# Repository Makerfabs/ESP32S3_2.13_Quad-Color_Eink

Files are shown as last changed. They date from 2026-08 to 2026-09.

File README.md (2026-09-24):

# MaTouch ESP32-S3 2.13 Quad-Color Eink

## Introduction

Our MaTouch ESP32-S3 2.13 Quad-Color E-Ink display is equipped with the KEGM021317E08 model from Qingyue Optoelectronics, which adopts active matrix TFT microcapsule electrophoretic display technology to render images. This technology operates by applying an electric field to charged pigment particles suspended inside transparent microcapsules. Colored particles migrate to the microcapsule surfaces and reflect ambient light to form visible patterns, delivering a paper-like viewing experience identical to physical printed media. The EPD module features an active area resolution of 250(H) × 122(V) pixels, supporting 1-bit four-color display mode: black, white, red and yellow. Onboard peripheral expansion integrates the QMI8658A IMU sensor, which provides high-precision six-axis accelerometer and gyroscope data for motion detection, posture sensing and interactive control development.

Product Link: [MaTouch ESP32-S3 2.13 Quad-Color Eink](https://www.makerfabs.com/matouch-esp32-s3-2-13-quad-color-eink-epaper.html)

Wiki Link:  [MaTouch ESP32-S3 2.13 Quad-Color Eink](https://wiki.makerfabs.com/MaTouch%20ESP32_S3%202.13%20Quad_Color%20Eink.html)

Example：1.[SD_pic_display](https://github.com/Makerfabs/ESP32S3_2.13_Quad-Color_Eink#sd_pic_display)

2.[EPD_Pose_Display](https://github.com/Makerfabs/ESP32S3_2.13_Quad-Color_Eink#epd_pose_display)

## LCD Specs:

- PART NUMBER：KEGM021317E08
- SIZE：2.13 inch
- TYPE：Dot Matrix
- IC：JD79676
- RESOLUTION：250 × 122
- OUTLINE SIZE (mm)：75.2 × 29.2 × 0.911
- ACTIVE SIZE (mm)：48.55 × 23.7046
- PIXEL PITCH (mm)：0.1942 × 0.1943
- OPERATING TEMP.：0°C ~ 40°C
- STORAGE TEMP.：-25°C ~ 60°C
- CONNECTOR：24 Pin FPC
- COLOR：Black, White, Red, Yellow
- INTERFACE：SPI
- FULL REFRESH (S)：20

## Features

- Controller: ESP32-S3
- Wireless: WiFi& Bluetooth 5.0
- Flash:16MB Flash
- PSRAM:8MB
- MICRO SD: Yes
- IMU:QMI8658A
- USB:1 * USB_native
- Arduino support: Yes

## Example

### SD_pic_display

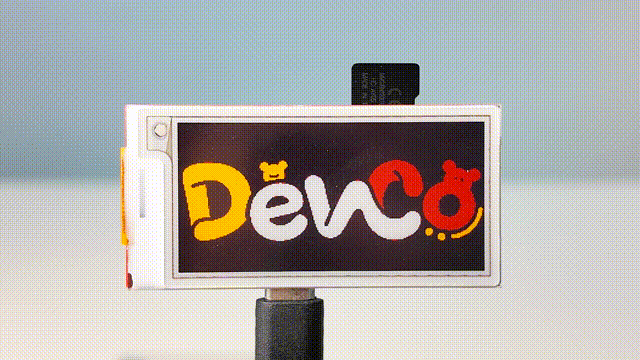
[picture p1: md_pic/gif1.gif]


For details of this example, please refer to the [Wiki](https://wiki.makerfabs.com/MaTouch%20ESP32_S3%202.13%20Quad_Color%20Eink.html#41-sd_pic_display) document.

### EPD_Pose_Display

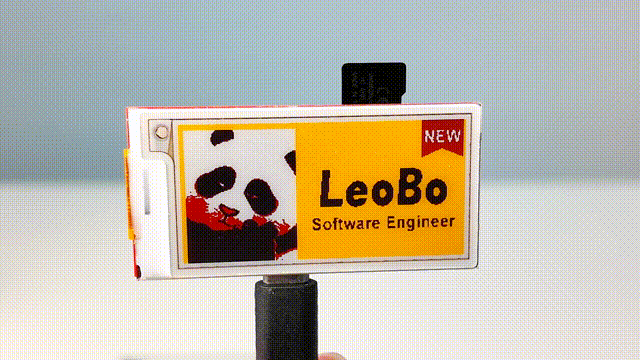
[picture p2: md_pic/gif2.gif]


For details of this example, please refer to the [Wiki](https://wiki.makerfabs.com/MaTouch%20ESP32_S3%202.13%20Quad_Color%20Eink.html#42-epd_pose_display) document.

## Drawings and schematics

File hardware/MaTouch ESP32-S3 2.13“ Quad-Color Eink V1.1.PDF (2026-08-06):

# POWER

# USB

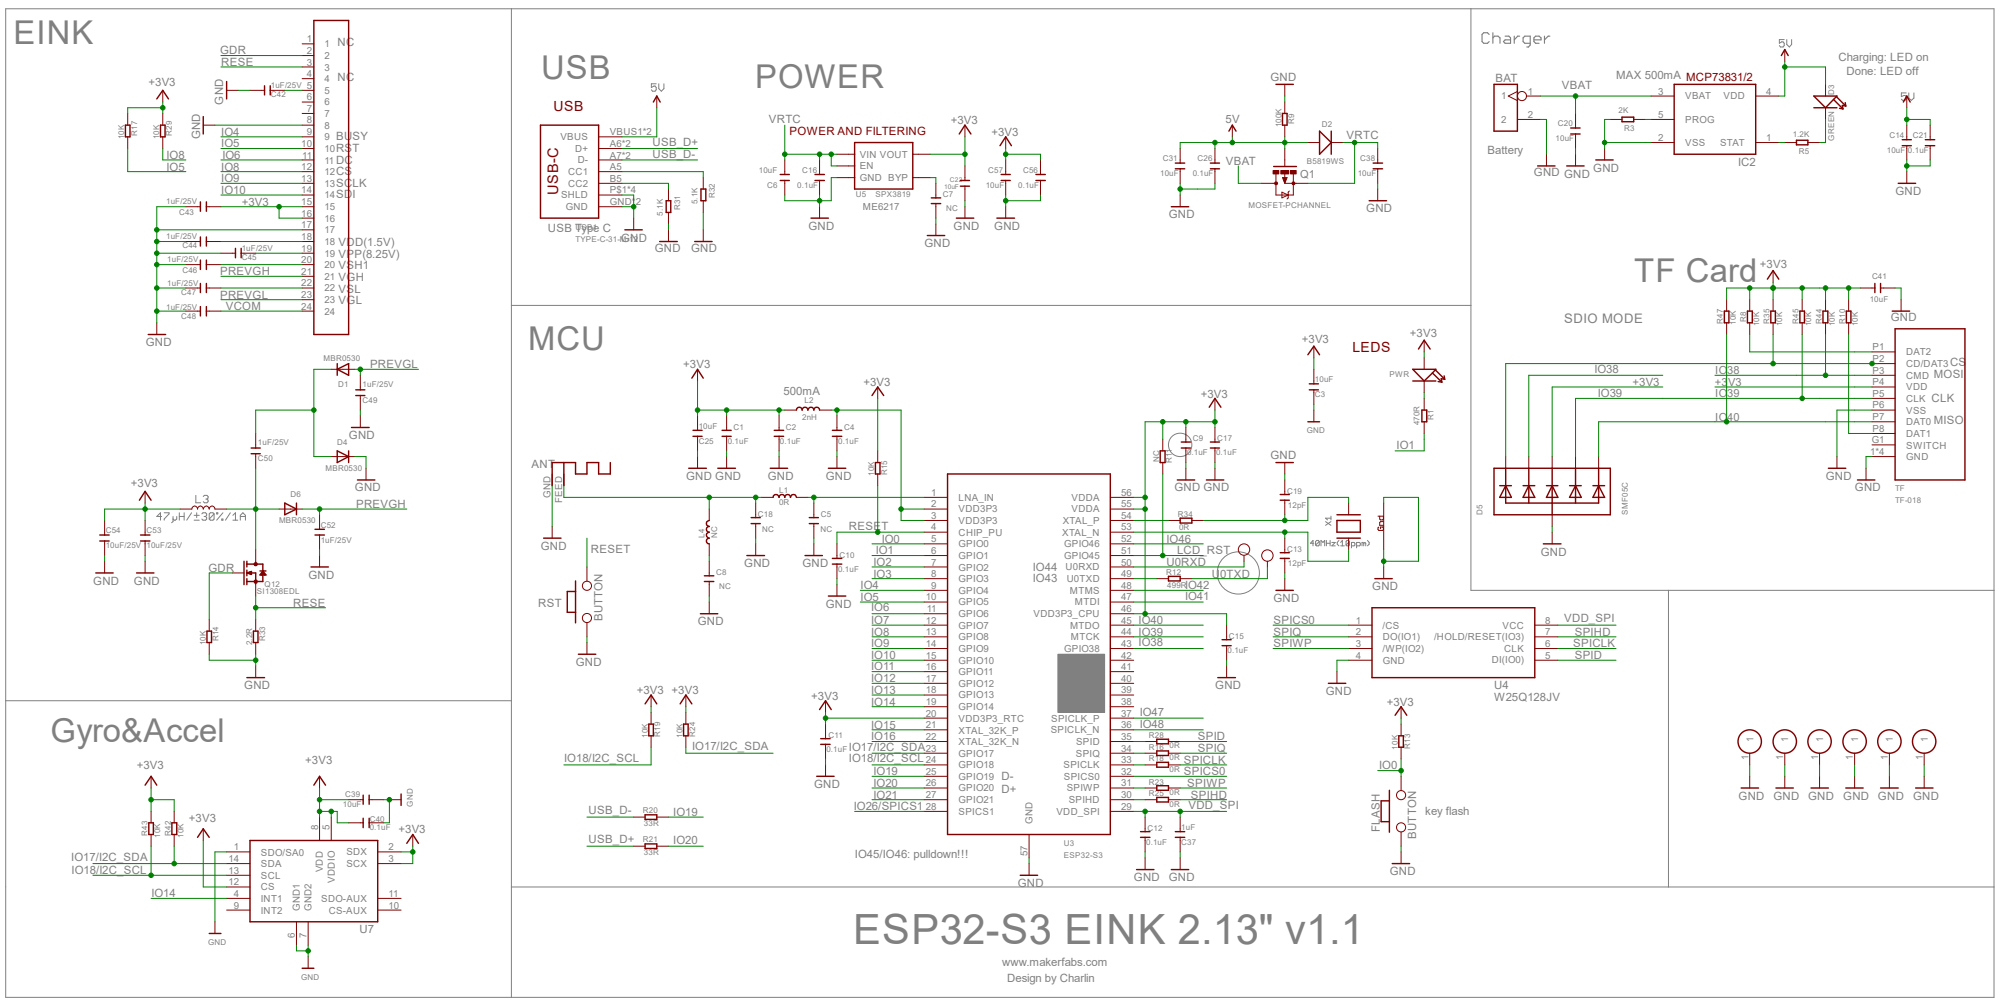
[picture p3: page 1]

VSS P6

DAT1 P8

GND GND

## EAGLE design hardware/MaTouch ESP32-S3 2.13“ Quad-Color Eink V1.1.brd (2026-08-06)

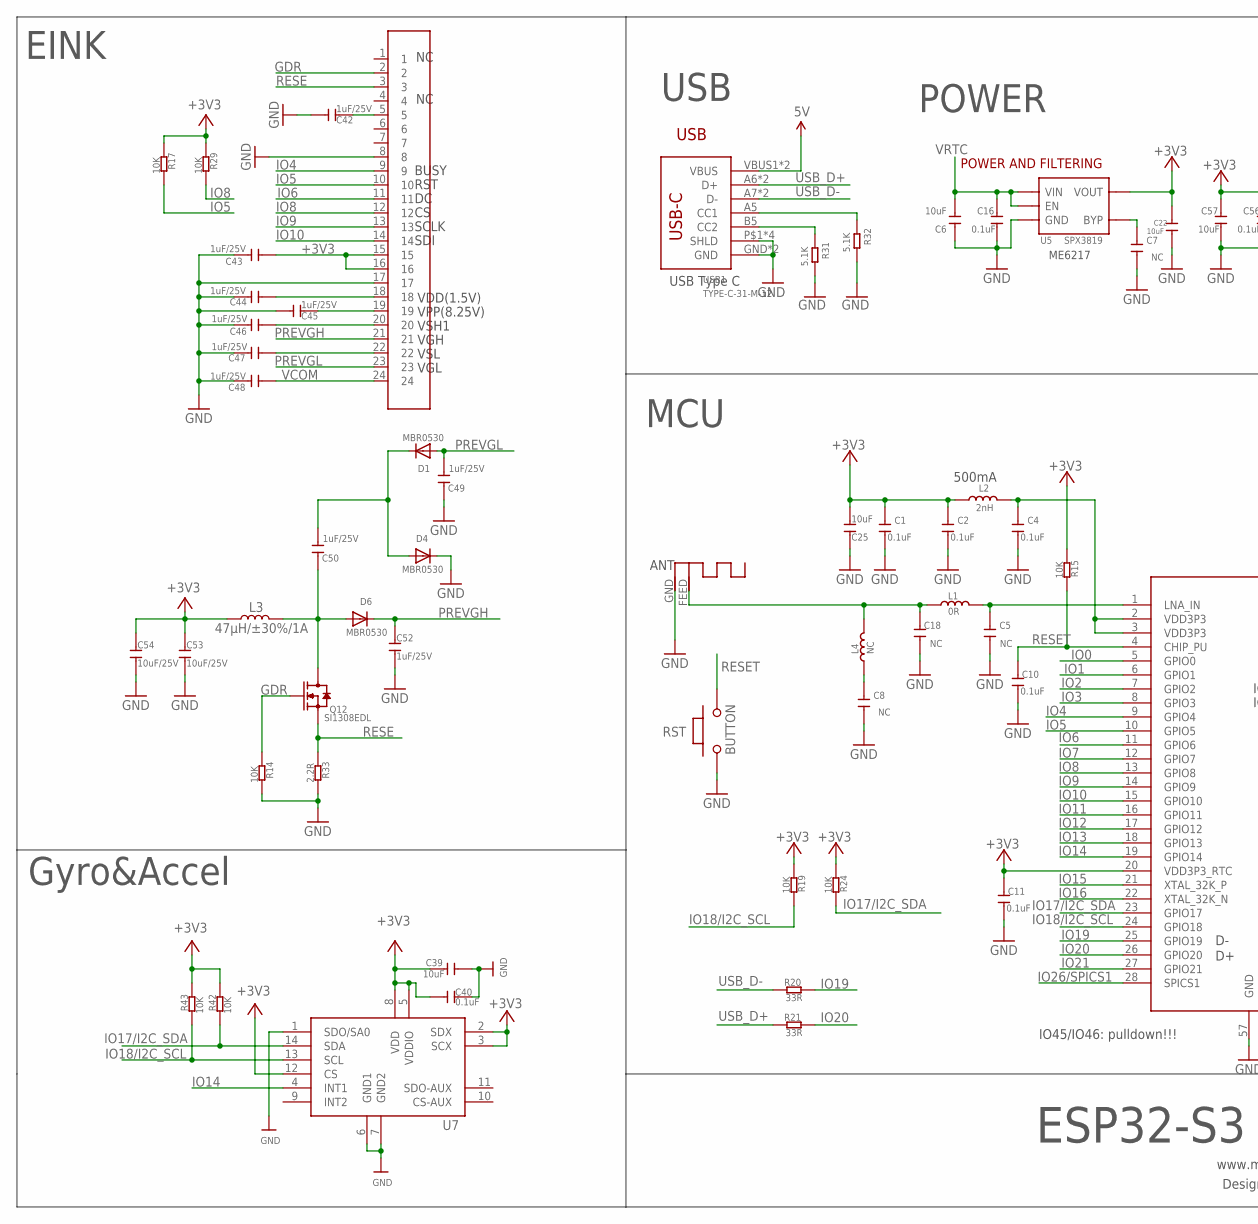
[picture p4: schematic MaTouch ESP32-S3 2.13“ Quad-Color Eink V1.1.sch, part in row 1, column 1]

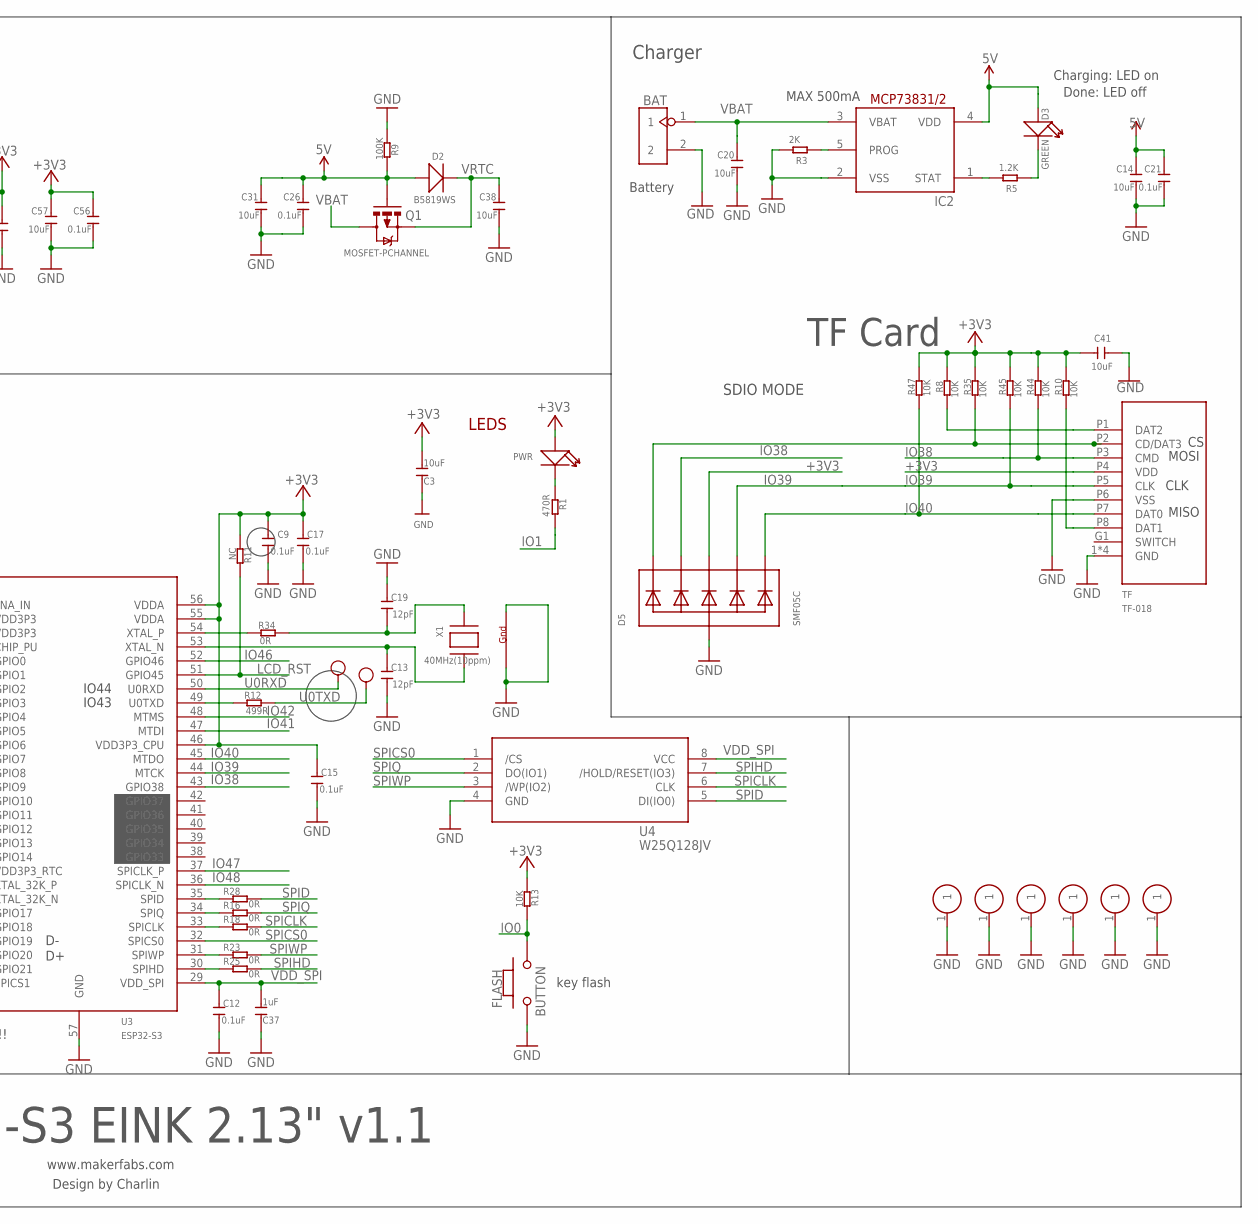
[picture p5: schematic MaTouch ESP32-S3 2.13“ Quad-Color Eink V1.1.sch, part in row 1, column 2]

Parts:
ANT1: ANTENNA; RN-ANT
BAT: HEADER-2P-2.0; 2P-2.0
C1, C2, C4, C9, C10, C11, C12, C15, C16, C17, C21, C26, C40, C56: 0.1uF; DISCRETE_C0402
C3, C6, C25: 10uF; DISCRETE_C0603
C5, C7, C8, C18: NC; DISCRETE_C0402
C13, C19: 12pF; DISCRETE_C0402
C14, C20, C31, C38, C39, C41, C57: 10uF; DISCRETE_C0402
C22: 10uF; 0603
C37: 1uF; DISCRETE_C0603
C42, C43, C44, C45, C46, C47, C48, C49, C50: 1uF/25V; DISCRETE_C0402
C52: 1uF/25V; 0603
C53, C54: 10uF/25V; 0603
D1, D4, D6: MBR0530; SOD-323F
D2: B5819WS; SOD323
D3: GREEN; DISCRETE_LED-0603
D5: SMF05C; SOT363
FLASH: BUTTON; 157SW
IC2: TP4054; SOT23-5L
J1: FPC24-80P-A; SMD24-80P-1960L440W
L1: 0R; DISCRETE_L0402
L2: 2nH; DISCRETE_L0603
L3: 47µH/±30%/1A; CR54
L4: NC; DISCRETE_L0402
PWR: DISCRETE_LED0603; DISCRETE_LED-0603
Q1: MOSFET-PCHANNEL; SOT23-3
Q12: SI1308EDL; SOT23
R1: 470R; DISCRETE_R0402
R3: 2K; DISCRETE_R0402
R5: 1.2K; DISCRETE_R0402
R8, R10, R13, R14, R15, R17, R19, R24, R29, R35, R42, R43, R44, R45, R47: 10K; DISCRETE_R0402
R9: 100K; DISCRETE_R0402
R11: NC; DISCRETE_R0402
R12: 499R; DISCRETE_R0402
R16, R18, R23, R25, R28, R34: 0R; DISCRETE_R0402
R20, R21: 33R; DISCRETE_R0402
R31, R32: 5.1K; DISCRETE_R0402
R33: 2.2R; DISCRETE_R0402
RST: BUTTON; 157SW
RX: TEST-POINT'4545'; TP-D45MIL; PARTNO DNP
S1, S2, S3, S4, S5, S6: ONEPIN01
TF: TF-018
TX: TEST-POINT'4545'; TP-D45MIL; PARTNO DNP
U3: ESP32-S3; QFN56-7*7MM
U4: W25Q128JV; SOIC-8-208MIL
U5: SPX3819; SOT23-5
U7: QMI8658A; LGA14-50P-300L250W86H
USB1: TYPE-C-31-M-12
X1: 40MHz(10ppm); NX3225

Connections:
5V: C14.2, C21.2, C26.2, C31.2, D2.+, D3.+, IC2.4 (VDD), Q1.1 (G), R9.2, USB1.VBUS1 (VBUS), USB1.VBUS2 (VBUS)
+3V3: C1.2, C2.2, C3.2, C9.2, C11.2, C15.2, C17.2, C22.1, C25.2, C39.2, C40.2, C41.2, C43.1, C53.1, C54.1, C56.2, C57.2, D5.4 (C3), J1.15, J1.16, L2.1, L3.P$1 (1), PWR.+, R8.2, R10.2, R11.2, R13.2, R15.2, R17.1, R19.2, R24.2, R29.1, R35.2, R42.2, R43.2, R44.2, R45.2, R47.2, TF.P4 (VDD), U3.20 (VDD3P3_RTC), U3.46 (VDD3P3_CPU), U3.55 (VDDA), U3.56 (VDDA), U5.5 (VOUT), U7.2 (SDX), U7.3 (SCX), U7.5 (VDDIO), U7.8 (VDD), U7.12 (CS)
GDR: J1.2, Q12.1 (G), R14.1
GND: ANT1.GND, BAT.2, C1.1, C2.1, C3.1, C4.1, C5.1, C6.1, C7.1, C8.1, C9.1, C10.1, C11.1, C12.1, C13.1, C14.1, C15.1, C16.1, C17.1, C18.1, C19.2, C20.1, C21.1, C22.2, C25.1, C26.1, C31.1, C37.1, C38.1, C39.1, C40.1, C41.1, C42.2, C43.2, C44.2, C45.2, C46.2, C47.2, C48.2, C49.2, C52.2, C53.2, C54.2, C56.1, C57.1, D4.C, D5.2 (A), FLASH.1, IC2.2 (VSS), J1.8, J1.17, R3.2, R9.1, R14.2, R31.2, R32.2, R33.2, RST.1, S1.1, S2.1, S3.1, S4.1, S5.1, S6.1, TF.1 (GND), TF.2 (GND), TF.3 (GND), TF.4 (GND), TF.P6 (VSS), U3.57 (GND), U4.4 (GND), U5.2 (GND), U7.1 (SDO/SA0), U7.6 (GND1), U7.7 (GND2), USB1.GND, USB1.GND2 (GND), USB1.P$1 (SHLD), USB1.P$2 (SHLD), USB1.P$3 (SHLD), USB1.P$4 (SHLD), X1.2 (G2), X1.4 (G1)
IO0: FLASH.2, R13.1, U3.5 (GPIO0)
IO1: R1.1, U3.6 (GPIO1)
IO2: U3.7 (GPIO2)
IO3: U3.8 (GPIO3)
IO4: J1.9, U3.9 (GPIO4)
IO5: J1.10, R17.2, U3.10 (GPIO5)
IO6: J1.11, U3.11 (GPIO6)
IO7: U3.12 (GPIO7)
IO8: J1.12, R29.2, U3.13 (GPIO8)
IO9: J1.13, U3.14 (GPIO9)
IO10: J1.14, U3.15 (GPIO10)
IO11: U3.16 (GPIO11)
IO12: U3.17 (GPIO12)
IO13: U3.18 (GPIO13)
IO14: U3.19 (GPIO14), U7.4 (INT1)
IO15: U3.21 (XTAL_32K_P)
IO16: U3.22 (XTAL_32K_N)
IO17/I2C_SDA: R24.1, R42.1, U3.23 (GPIO17), U7.14 (SDA)
IO18/I2C_SCL: R19.1, R43.1, U3.24 (GPIO18), U7.13 (SCL)
IO19: R20.1, U3.25 (GPIO19)
IO20: R21.1, U3.26 (GPIO20)
IO21: U3.27 (GPIO21)
IO26/SPICS1: U3.28 (SPICS1)
IO38: D5.3 (C2), R44.1, TF.P3 (CMD), U3.43 (GPIO38)
IO39: D5.5 (C4), R45.1, TF.P5 (CLK), U3.44 (MTCK)
IO40: D5.6 (C5), R47.1, TF.P7 (DAT0), U3.45 (MTDO)
IO41: U3.47 (MTDI)
IO42: U3.48 (MTMS)
IO46: U3.52 (GPIO46)
IO47: U3.37 (SPICLK_P)
IO48: U3.36 (SPICLK_N)
LCD_RST: R11.1, U3.51 (GPIO45)
unnamed: ANT1.FEED, C18.2, L1.1, L4.2
unnamed: C5.2, L1.2, U3.1 (LNA_IN)
unnamed: R28.2, U3.35 (SPID)
unnamed: C8.2, L4.1
unnamed: R32.1, USB1.A5 (CC1)
unnamed: C42.1, J1.5
unnamed: PWR.-, R1.2
unnamed: C45.1, J1.19
unnamed: C46.1, J1.20
unnamed: C47.1, J1.22
unnamed: C50.1, D1.C, D4.A
unnamed: R8.1, TF.P1 (DAT2)
unnamed: C44.1, J1.18
unnamed: IC2.5 (PROG), R3.1
unnamed: R10.1, TF.P8 (DAT1)
unnamed: D5.1 (C1), R35.1, TF.P2 (CD/DAT3)
unnamed: IC2.1 (STAT), R5.2
unnamed: D3.-, R5.1
unnamed: C4.2, L2.2, U3.2 (VDD3P3), U3.3 (VDD3P3)
unnamed: R31.1, USB1.B5 (CC2)
unnamed: R16.2, U3.34 (SPIQ)
unnamed: R34.2, U3.54 (XTAL_P)
unnamed: R18.2, U3.33 (SPICLK)
unnamed: R23.2, U3.31 (SPIWP)
unnamed: R25.2, U3.30 (SPIHD)
unnamed: R12.2, U3.49 (U0TXD)
unnamed: C13.2, U3.53 (XTAL_N), X1.3 (X2)
unnamed: C19.1, R34.1, X1.1 (X1)
unnamed: C50.2, D6.A, L3.P$2 (2), Q12.3 (D)
unnamed: C7.2, U5.4 (BYP)
PREVGH: C52.1, D6.C, J1.21
PREVGL: C49.1, D1.A, J1.23
RESE: J1.3, Q12.2 (S), R33.1
RESET: C10.2, R15.1, RST.2, U3.4 (CHIP_PU)
SPICLK: R18.1, U4.6 (CLK)
SPICS0: U3.32 (SPICS0), U4.1 (/CS)
SPID: R28.1, U4.5 (DI(IO0))
SPIHD: R25.1, U4.7 (/HOLD/RESET(IO3))
SPIQ: R16.1, U4.2 (DO(IO1))
SPIWP: R23.1, U4.3 (/WP(IO2))
U0RXD: RX.T, U3.50 (U0RXD)
U0TXD: R12.1, TX.T
USB_D+: R21.2, USB1.A6 (D+), USB1.B6 (D+)
USB_D-: R20.2, USB1.A7 (D-), USB1.B7 (D-)
VBAT: BAT.1, C20.2, IC2.3 (VBAT), Q1.3 (D)
VCOM: C48.1, J1.24
VDD_SPI: C12.2, C37.2, U3.29 (VDD_SPI), U4.8 (VCC)
VRTC: C6.2, C16.2, C38.2, D2.-, Q1.2 (S), U5.1 (VIN), U5.3 (EN)

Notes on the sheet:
www.makerfabs.com
Design by Charlin
LEDS
POWER AND FILTERING
key flash
ESP32-S3 EINK 2.13" v1.1
POWER
MCU
ME6217
500mA
IO45/IO46: pulldown!!!
IO43
IO44
ANT
USB
USB Type C
Battery
Charging: LED on
Done: LED off
Charger
MAX 500mA
Gyro&Accel
SDIO MODE
TF Card
MOSI
CLK
MISO
EINK
VDD(1.5V)
VPP(8.25V)
VSH1
VGH
VSL
VGL
BUSY
RST
SCLK
SDI

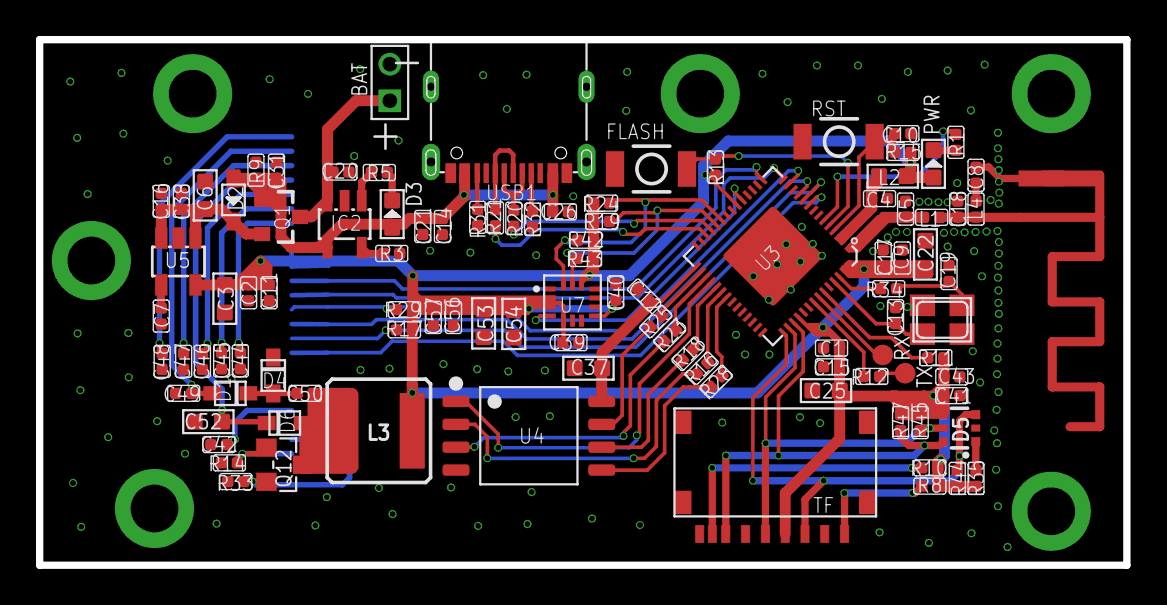
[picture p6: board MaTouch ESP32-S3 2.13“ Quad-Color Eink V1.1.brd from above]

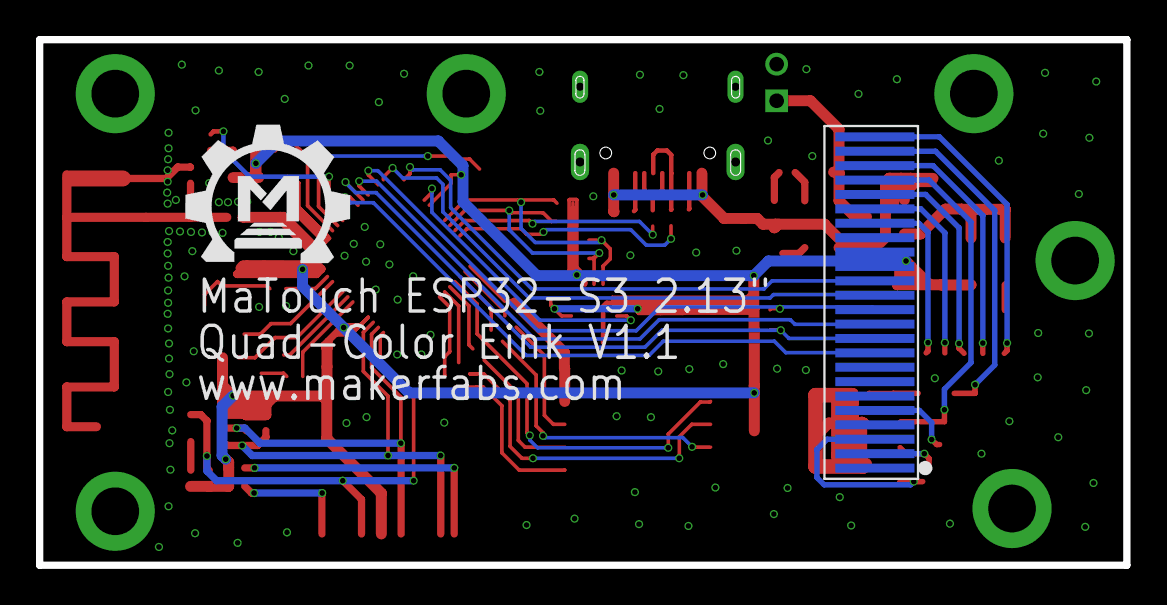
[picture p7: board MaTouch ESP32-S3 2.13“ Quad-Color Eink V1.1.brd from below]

Board: 2 copper layers, 60.4 x 29.2 mm, 111 parts (2 on the bottom side), 69 nets.

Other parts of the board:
U$1: MAKERFABS_0.3

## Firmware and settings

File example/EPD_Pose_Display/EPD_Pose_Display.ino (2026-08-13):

#include <SPI.h>
#include <FS.h>
#include <SD_MMC.h>
#include <Wire.h>
#include <math.h>

#include "Display_EPD_W21_spi.h"
#include "Display_EPD_W21.h"

// SD card pins from the MaTouch ESP32-S3 2.13-inch V1.0 schematic.
constexpr int SD_CLK_PIN = 39;
constexpr int SD_CMD_PIN = 38;
constexpr int SD_D0_PIN = 40;

// QMI8658A is already fitted on the board: I2C on GPIO17/18 and INT1 on GPIO14.
constexpr int IMU_SDA_PIN = 17;
constexpr int IMU_SCL_PIN = 18;
constexpr int IMU_INT_PIN = 14;
constexpr uint8_t QMI8658A_WHO_AM_I = 0x05;

// QMI8658A register addresses used by this sketch.
constexpr uint8_t QMI8658A_REG_WHO_AM_I = 0x00;
constexpr uint8_t QMI8658A_REG_CTRL1 = 0x02;
constexpr uint8_t QMI8658A_REG_CTRL2 = 0x03;
constexpr uint8_t QMI8658A_REG_CTRL3 = 0x04;
constexpr uint8_t QMI8658A_REG_CTRL7 = 0x08;
constexpr uint8_t QMI8658A_REG_AX_L = 0x35;

// The accelerometer is configured for +/-8 g at 1 kHz.  A valid pose must be
// close to one gravity and remain unchanged before the EPD is refreshed.
constexpr float QMI8658A_ACCEL_G_PER_LSB = 8.0f / 32768.0f;
constexpr unsigned long POSE_SAMPLE_INTERVAL_MS = 50;
constexpr unsigned long POSE_STABLE_TIME_MS = 500;
constexpr unsigned long POSE_DIAGNOSTIC_INTERVAL_MS = 500;
constexpr float POSE_GRAVITY_MIN_G = 0.80f;
constexpr float POSE_GRAVITY_MAX_G = 1.20f;
constexpr float POSE_MATCH_MIN_DOT_PRODUCT = 0.80f;

// Image2Lcd is configured as: 250 x 128, vertical scan, 4 gray levels.
constexpr uint16_t BMP_WIDTH = 250;
constexpr uint16_t BMP_HEIGHT = 128;
constexpr uint16_t BYTES_PER_COLUMN = BMP_HEIGHT / 4; // Four 2-bit pixels/byte.

const char *const kImageFiles[] = {"/image1.bmp", "/image2.bmp", "/image3.bmp"};

struct PoseTarget {
  float gravityX;
  float gravityY;
  float gravityZ;
  uint8_t imageIndex;
  const char *name;
};

// These three vectors describe the gravity direction measured by the IMU for
// photos 1, 2 and 3.  The assumed board axes are useful starting values.  Use
// the "IMU g" serial output after flashing to adjust only these values if the
// installed IMU orientation differs from the assumption.
const PoseTarget kPoseTargets[] = {
    {0.0f, -1.0f, 0.0f, 0, "photo 1 / LeoBo"},
    {-1.0f, 0.0f, 0.0f, 1, "photo 2 / cherry"},
    {0.0f, 1.0f, 0.0f, 2, "photo 3 / Makerfabs"},
};
constexpr size_t POSE_TARGET_COUNT = sizeof(kPoseTargets) / sizeof(kPoseTargets[0]);

uint8_t imageBuffer[EPD_ARRAY];
uint8_t qmi8658aAddress = 0;

static bool readBytes(File &file, uint8_t *buffer, size_t count)
{
  return file.read(buffer, count) == count;
}

static uint16_t readLE16(const uint8_t *p)
{
  return static_cast<uint16_t>(p[0]) |
         (static_cast<uint16_t>(p[1]) << 8);
}

static uint32_t readLE32(const uint8_t *p)
{
  return static_cast<uint32_t>(p[0]) |
         (static_cast<uint32_t>(p[1]) << 8) |
         (static_cast<uint32_t>(p[2]) << 16) |
         (static_cast<uint32_t>(p[3]) << 24);
}

static bool qmi8658aWriteRegister(uint8_t reg, uint8_t value)
{
  if (qmi8658aAddress == 0) {
    return false;
  }
  Wire.beginTransmission(qmi8658aAddress);
  Wire.write(reg);
  Wire.write(value);
  return Wire.endTransmission() == 0;
}

static bool qmi8658aReadRegisters(uint8_t reg, uint8_t *buffer, size_t count)
{
  if (qmi8658aAddress == 0) {
    return false;
  }
  Wire.beginTransmission(qmi8658aAddress);
  Wire.write(reg);
  if (Wire.endTransmission(false) != 0) {
    return false;
  }

  const size_t received = Wire.requestFrom(static_cast<uint8_t>(qmi8658aAddress),
                                           static_cast<uint8_t>(count));
  if (received != count) {
    return false;
  }

  for (size_t i = 0; i < count; ++i) {
    buffer[i] = Wire.read();
  }
  return true;
}

static bool initImu()
{
  Wire.begin(IMU_SDA_PIN, IMU_SCL_PIN);
  Wire.setClock(400000);

  // The reference hardware test searches both valid QMI8658A addresses.  The
  // schematic uses 0x6A, but an assembled board can use 0x6B if SA0 differs.
  const uint8_t addresses[] = {0x6A, 0x6B};
  for (uint8_t address : addresses) {
    qmi8658aAddress = address;
    uint8_t chipId = 0;
    if (qmi8658aReadRegisters(QMI8658A_REG_WHO_AM_I, &chipId, 1) &&
        chipId == QMI8658A_WHO_AM_I) {
      Serial.printf("QMI8658A found at I2C address 0x%02X\n", qmi8658aAddress);
      break;
    }
    qmi8658aAddress = 0;
  }
  if (qmi8658aAddress == 0) {
    Serial.println("QMI8658A not found at I2C address 0x6A or 0x6B");
    return false;
  }

  // These are the known-good settings from the board's hardware test:
  // CTRL2: +/-8 g accelerometer; CTRL3: gyroscope; CTRL7: enable both.
  if (!qmi8658aWriteRegister(QMI8658A_REG_CTRL1, 0x60) ||
      !qmi8658aWriteRegister(QMI8658A_REG_CTRL2, 0x23) ||
      !qmi8658aWriteRegister(QMI8658A_REG_CTRL3, 0x53) ||
      !qmi8658aWriteRegister(QMI8658A_REG_CTRL7, 0x03)) {
    Serial.println("QMI8658A configuration failed");
    return false;
  }

  delay(100); // Allow a cold-started IMU to produce its first sample.
  pinMode(IMU_INT_PIN, INPUT);
  Serial.println("QMI8658A ready: place the board in one of the three configured directions");
  return true;
}

static bool readAccelerometerG(float &ax, float &ay, float &az)
{
  uint8_t data[6];
  if (!qmi8658aReadRegisters(QMI8658A_REG_AX_L, data, sizeof(data))) {
    return false;
  }

  const int16_t rawX = static_cast<int16_t>(static_cast<uint16_t>(data[0]) |
                                             (static_cast<uint16_t>(data[1]) << 8));
  const int16_t rawY = static_cast<int16_t>(static_cast<uint16_t>(data[2]) |
                                             (static_cast<uint16_t>(data[3]) << 8));
  const int16_t rawZ = static_cast<int16_t>(static_cast<uint16_t>(data[4]) |
                                             (static_cast<uint16_t>(data[5]) << 8));
  ax = rawX * QMI8658A_ACCEL_G_PER_LSB;
  ay = rawY * QMI8658A_ACCEL_G_PER_LSB;
  az = rawZ * QMI8658A_ACCEL_G_PER_LSB;
  return true;
}

// Returns the selected image index, or -1 while the device is moving, tilted,
// or in a direction not assigned to a picture.
static int detectPoseImage(float ax, float ay, float az)
{
  const float magnitudeG = sqrtf(ax * ax + ay * ay + az * az);
  if (magnitudeG < POSE_GRAVITY_MIN_G || magnitudeG > POSE_GRAVITY_MAX_G) {
    return -1;
  }

  const float normalizedX = ax / magnitudeG;
  const float normalizedY = ay / magnitudeG;
  const float normalizedZ = az / magnitudeG;
  float bestDotProduct = -1.0f;
  int bestImageIndex = -1;

  for (size_t i = 0; i < POSE_TARGET_COUNT; ++i) {
    const PoseTarget &target = kPoseTargets[i];
    const float dotProduct = normalizedX * target.gravityX +
                             normalizedY * target.gravityY +
                             normalizedZ * target.gravityZ;
    if (dotProduct > bestDotProduct) {
      bestDotProduct = dotProduct;
      bestImageIndex = target.imageIndex;
    }
  }

  return bestDotProduct >= POSE_MATCH_MIN_DOT_PRODUCT ? bestImageIndex : -1;
}

// A pose is accepted only after it remains unchanged for POSE_STABLE_TIME_MS.
// This prevents an update while the board is being turned or carried.
static int confirmedPoseImage()
{
  static unsigned long lastSampleMs = 0;
  static unsigned long lastDiagnosticMs = 0;
  static unsigned long candidateSinceMs = 0;
  static int candidateImageIndex = -1;

  const unsigned long now = millis();
  if (now - lastSampleMs < POSE_SAMPLE_INTERVAL_MS) {
    return -1;
  }
  lastSampleMs = now;

  float ax, ay, az;
  if (!readAccelerometerG(ax, ay, az)) {
    candidateImageIndex = -1;
    return -1;
  }

  const int imageIndex = detectPoseImage(ax, ay, az);
  if (now - lastDiagnosticMs >= POSE_DIAGNOSTIC_INTERVAL_MS) {
    lastDiagnosticMs = now;
    if (imageIndex >= 0) {
      Serial.printf("IMU g: ax=%+.2f ay=%+.2f az=%+.2f; pose=%d\n", ax, ay, az, imageIndex + 1);
    } else {
      Serial.printf("IMU g: ax=%+.2f ay=%+.2f az=%+.2f; pose=none\n", ax, ay, az);
    }
  }

  if (imageIndex != candidateImageIndex) {
    candidateImageIndex = imageIndex;
    candidateSinceMs = now;
    return -1;
  }
  if (imageIndex < 0 || now - candidateSinceMs < POSE_STABLE_TIME_MS) {
    return -1;
  }
  return imageIndex;
}

// Convert RGB to the four source values expected by PIC_display().
// 0 = white, 1 = yellow, 2 = red, 3 = black after Color_get().
static uint8_t rgbToFourColor(uint8_t redChannel, uint8_t greenChannel, uint8_t blueChannel)
{
  const uint8_t luminance = static_cast<uint8_t>(
      (77U * redChannel + 150U * greenChannel + 29U * blueChannel) >> 8);

  // Detect the two chromatic panel colors before applying grayscale thresholds.
  // A pure yellow has high R/G and a low B component, but is bright enough to
  // otherwise be mistaken for white by a luminance-only conversion.
  if (redChannel >= 150 && greenChannel >= 120 && blueChannel <= 120 &&
      redChannel + 70 >= greenChannel) {
    return 1; // yellow
  }
  if (redChannel >= 130 && redChannel >= greenChannel + 45 &&
      redChannel >= blueChannel + 45) {
    return 2; // red
  }

  if (luminance >= 160) return 0; // white
  if (luminance < 90) return 3;   // black

  // Treat all neutral midtones as white. This keeps anti-aliased edges and
  // light gray image areas clean instead of rendering them as red or black.
  return 0;
}

// Load an uncompressed 250 x 128 BMP. Both 24-bit BGR and 32-bit BGRA files
// are accepted. The output layout intentionally follows Image2Lcd's vertical
// scan option, so the horizontal 250 x 128 picture is not rotated.
static bool loadBmp250x128(const char *path)
{
  File file = SD_MMC.open(path, FILE_READ);
  if (!file) {
    Serial.printf("Cannot open %s\n", path);
    return false;
  }

  uint8_t header[54];
  if (!readBytes(file, header, sizeof(header)) || header[0] != 'B' || header[1] != 'M') {
    Serial.printf("%s is not a BMP file\n", path);
    file.close();
    return false;
  }

  const uint32_t pixelOffset = readLE32(header + 10);
  const uint32_t dibSize = readLE32(header + 14);
  const int32_t width = static_cast<int32_t>(readLE32(header + 18));
  const int32_t rawHeight = static_cast<int32_t>(readLE32(header + 22));
  const uint16_t planes = readLE16(header + 26);
  const uint16_t bitsPerPixel = readLE16(header + 28);
  const uint32_t compression = readLE32(header + 30);

  const int32_t height = rawHeight < 0 ? -rawHeight : rawHeight;
  if (dibSize < 40 || width != BMP_WIDTH || height != BMP_HEIGHT || planes != 1 ||
      (bitsPerPixel != 24 && bitsPerPixel != 32) || compression != 0) {
    Serial.printf("Unsupported BMP: %ld x %ld, %u bpp, compression %lu\n",
                  static_cast<long>(width), static_cast<long>(rawHeight),
                  bitsPerPixel, static_cast<unsigned long>(compression));
    file.close();
    return false;
  }

  const uint8_t bytesPerPixel = bitsPerPixel / 8;
  const uint32_t rowStride = ((static_cast<uint32_t>(width) * bitsPerPixel + 31U) / 32U) * 4U;
  uint8_t row[1000]; // 250 pixels x 4 bytes; enough for 24-bit padded rows too.
  memset(imageBuffer, 0, sizeof(imageBuffer));

  for (uint16_t sourceY = 0; sourceY < BMP_HEIGHT; ++sourceY) {
    // Positive BMP heights are stored bottom-to-top. Convert only the file row
    // order here; it does not rotate or mirror the intended image.
    const uint16_t fileY = rawHeight > 0 ? BMP_HEIGHT - 1 - sourceY : sourceY;
    if (!file.seek(pixelOffset + static_cast<uint32_t>(fileY) * rowStride) ||
        !readBytes(file, row, rowStride)) {
      Serial.printf("Read failed at BMP row %u\n", sourceY);
      file.close();
      return false;
    }

    for (uint16_t sourceX = 0; sourceX < BMP_WIDTH; ++sourceX) {
      const uint8_t *pixel = row + sourceX * bytesPerPixel; // BMP stores B, G, R, [A].
      const uint8_t color = rgbToFourColor(pixel[2], pixel[1], pixel[0]);

      // Image2Lcd vertical scan: finish one 128-pixel column before the next.
      const size_t index = static_cast<size_t>(sourceX) * BYTES_PER_COLUMN + sourceY / 4;
      const uint8_t shift = 6 - 2 * (sourceY & 0x03);
      imageBuffer[index] |= color << shift;
    }
  }

  file.close();
  return true;
}

static void showImage(const char *path)
{
  Serial.printf("Loading %s\n", path);
  if (!loadBmp250x128(path)) {
    return;
  }

  EPD_init();
  PIC_display(imageBuffer);
  EPD_sleep();
  Serial.println("Display refreshed");
}

void setup()
{
  Serial.begin(115200);
  delay(200);

  pinMode(EPD_BUSY_PIN, INPUT);
  pinMode(EPD_RST_PIN, OUTPUT);
  pinMode(EPD_DC_PIN, OUTPUT);
  pinMode(EPD_CS_PIN, OUTPUT);
  SPI.begin(EPD_SCK_PIN, -1, EPD_MOSI_PIN, EPD_CS_PIN);
  SPI.beginTransaction(SPISettings(10000000, MSBFIRST, SPI_MODE0));

  SD_MMC.setPins(SD_CLK_PIN, SD_CMD_PIN, SD_D0_PIN);
  // The final false prevents SD_MMC from formatting a card when mount fails.
  if (!SD_MMC.begin("/sdcard", true, false)) {
    Serial.println("SD card mount failed");
    while (true) delay(1000);
  }

  Serial.printf("SD card: %llu MB\n", SD_MMC.cardSize() / (1024ULL * 1024ULL));

  if (!initImu()) {
    Serial.println("IMU unavailable: check that U7 is fitted and its I2C lines are intact");
    while (true) delay(1000);
  }
}

void loop()
{
  static int displayedImageIndex = -1;

  const int poseImageIndex = confirmedPoseImage();
  if (poseImageIndex >= 0 && poseImageIndex != displayedImageIndex) {
    Serial.printf("Pose confirmed: %s\n", kPoseTargets[poseImageIndex].name);
    showImage(kImageFiles[poseImageIndex]);
    displayedImageIndex = poseImageIndex;
  }
}

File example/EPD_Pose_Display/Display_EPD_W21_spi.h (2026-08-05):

#ifndef _DISPLAY_EPD_W21_SPI_
#define _DISPLAY_EPD_W21_SPI_
#include "Arduino.h"

// MaTouch ESP32-S3 2.13-inch Quad-Color E-Ink V1.0 schematic pinout.
#define EPD_BUSY_PIN 4
#define EPD_RST_PIN 5
#define EPD_DC_PIN 6
#define EPD_CS_PIN 8
#define EPD_SCK_PIN 9
#define EPD_MOSI_PIN 10

#define isEPD_W21_BUSY digitalRead(EPD_BUSY_PIN)
#define EPD_W21_RST_0 digitalWrite(EPD_RST_PIN, LOW)
#define EPD_W21_RST_1 digitalWrite(EPD_RST_PIN, HIGH)
#define EPD_W21_DC_0  digitalWrite(EPD_DC_PIN, LOW)
#define EPD_W21_DC_1  digitalWrite(EPD_DC_PIN, HIGH)
#define EPD_W21_CS_0 digitalWrite(EPD_CS_PIN, LOW)
#define EPD_W21_CS_1 digitalWrite(EPD_CS_PIN, HIGH)


void SPI_Write(unsigned char value);
void EPD_W21_WriteDATA(unsigned char datas);
void EPD_W21_WriteCMD(unsigned char command);


#endif 

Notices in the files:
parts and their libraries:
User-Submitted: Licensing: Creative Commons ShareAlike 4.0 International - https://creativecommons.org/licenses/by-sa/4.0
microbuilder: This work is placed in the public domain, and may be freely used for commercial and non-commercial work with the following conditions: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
